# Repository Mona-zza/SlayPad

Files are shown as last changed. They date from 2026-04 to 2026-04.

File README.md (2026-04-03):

# SlayPad

This is a 12key hackpad with 1 rotay Encoder, and 3 RGB LEDs. I've used "XIAO RP2040" microcontroller in it. For the CAD I made it in two parts "Top" and "Bottom". The over all Hackpad looks came up really awsome🎀. I'm so exicted to build this!!!

Currently JLPCB has a sale discount going in it so the PCB in screenshot is $2 cheapper, but I don't know wether that dicount will be there when I'll get the grant so I added $2 extra on PCB to cover it up if I don't get dicount that that moment.

# Images












# BOM

| Name | Purpose | Qty | Total (USD) | Distributor |
|---|---|-----|---|---|
| PCB | PCB | 1 | $15.00 | JLCPCB |
| Keycaps | Keycaps | 12  | $6.56 | Amazon |
| MX-Style switches | Keys | 20  | $6.47 | Amazon |
| 1N4148 Diodes | Diodes | 1 | $1.07 | Amazon |
| MINI-E RGB LEDs | RGB Leds | 1 | $1.24 | Amazon |
| EC11 Rotary Encoders| Volume switch | 1 | $1.86 | Amazon |
| XIAO RP2040 | Microcontroller | 1 | $19.97 | Amazon |
| **TOTAL** | | | **$52.17**  | |

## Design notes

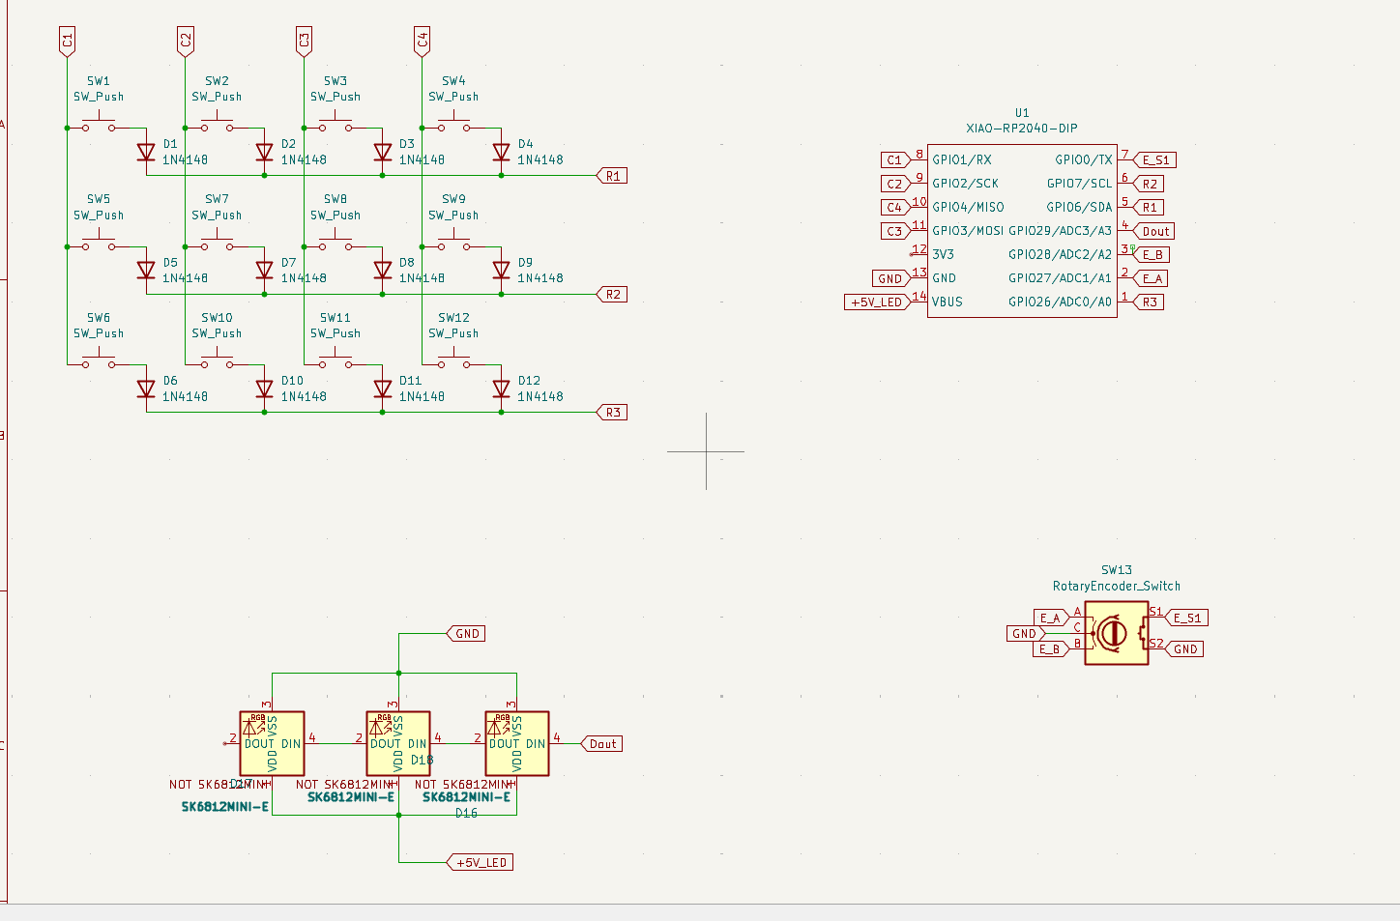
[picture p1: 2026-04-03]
Images/image.png

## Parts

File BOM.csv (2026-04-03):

Name | Purpose | Qty | Total (USD) | Link | Distributor
PCB | PCB | 1 | 15 |  | JLCPCB
Keycaps | Keycaps | 12 | 6.56 | https://www.amazon.in/gp/product/B0FY62LBWH | Amazon
MX-Style switches | Keys | 20 | 6.47 | https://www.amazon.in/gp/product/B0FQBYCGRR | Amazon
1N4148 Diodes | Diodes | 1 | 1.07 | https://www.amazon.in/gp/product/B0G8K9GW3F | Amazon
MINI-E RGB LEDs | RGB Leds | 1 | 1.24 | https://www.amazon.in/gp/product/B07L13JTF4 | Amazon
EC11 Rotary Encoders | Volume switch | 1 | 1.86 | https://www.amazon.in/gp/product/B0888RWNM1 | Amazon
XIAO RP2040 | Microcontroller | 1 | 19.97 | https://www.amazon.in/gp/product/B09NNVNW7M | Amazon
Total |  |  |  | 52.17

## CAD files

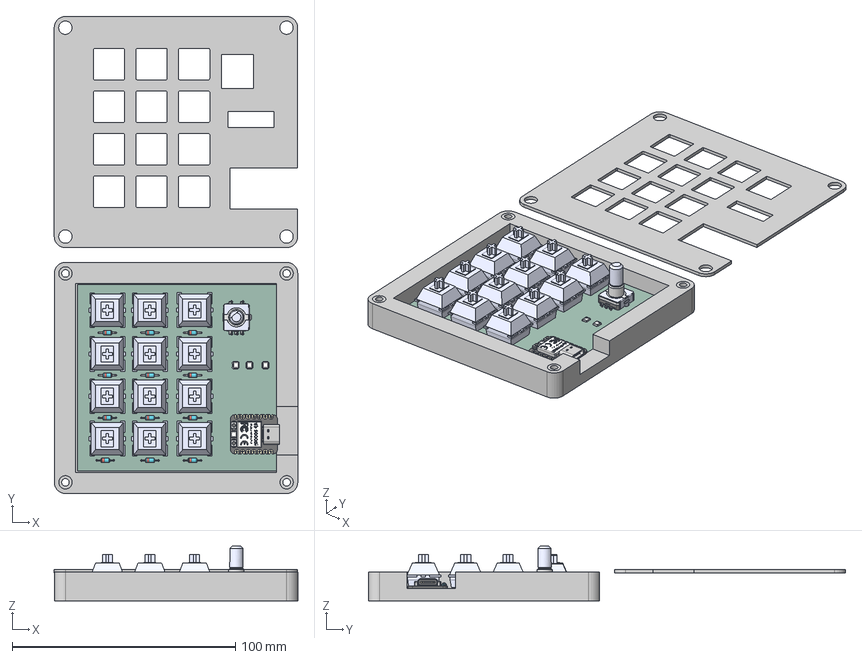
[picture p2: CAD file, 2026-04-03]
CAD/Macropad Assembly - 1.step
109.0 x 213.5 x 24.5 mm
EC11-Shaft-F
EC11-Housing-THT
EC11-Housing-THT_1
EC11-Housing-THT_2
EC11-Housing-THT_3
EC11-Housing-THT_4
EC11-Housing-THT_5
EC11-Housing-THT_6
EC11-Base
Seeed Studio XIAO RP2040 v26_1
Seeed Studio XIAO RP2040 v26_2
Seeed Studio XIAO RP2040 v26_3
Seeed Studio XIAO RP2040 v26_4
Seeed Studio XIAO RP2040 v26_5
Seeed Studio XIAO RP2040 v26_6
Seeed Studio XIAO RP2040 v26_7
Seeed Studio XIAO RP2040 v26_8
Seeed Studio XIAO RP2040 v26_9
Seeed Studio XIAO RP2040 v26_10
Seeed Studio XIAO RP2040 v26_11
Seeed Studio XIAO RP2040 v26_12
Seeed Studio XIAO RP2040 v26_13
Seeed Studio XIAO RP2040 v26_14
Seeed Studio XIAO RP2040 v26_15
Seeed Studio XIAO RP2040 v26_16
Seeed Studio XIAO RP2040 v26_17
Seeed Studio XIAO RP2040 v26_18
Seeed Studio XIAO RP2040 v26_19
Seeed Studio XIAO RP2040 v26_20
Seeed Studio XIAO RP2040 v26_21
Seeed Studio XIAO RP2040 v26_22
Seeed Studio XIAO RP2040 v26_23
Seeed Studio XIAO RP2040 v26_24
Seeed Studio XIAO RP2040 v26_25
Seeed Studio XIAO RP2040 v26_26
Seeed Studio XIAO RP2040 v26_27
Seeed Studio XIAO RP2040 v26_28
Seeed Studio XIAO RP2040 v26_29
Seeed Studio XIAO RP2040 v26_30
Seeed Studio XIAO RP2040 v26_31
Seeed Studio XIAO RP2040 v26_32
Seeed Studio XIAO RP2040 v26_33
Seeed Studio XIAO RP2040 v26_34
Seeed Studio XIAO RP2040 v26_35
Seeed Studio XIAO RP2040 v26_36
type-c v2
smd_button v3(Mirror)
main
main_1
main_2
main_3
type-c v2_1
type-c v2_2
type-c v2_3
type-c v2_4
main_4
main_5
main_6
type-c v2_5
type-c v2_6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

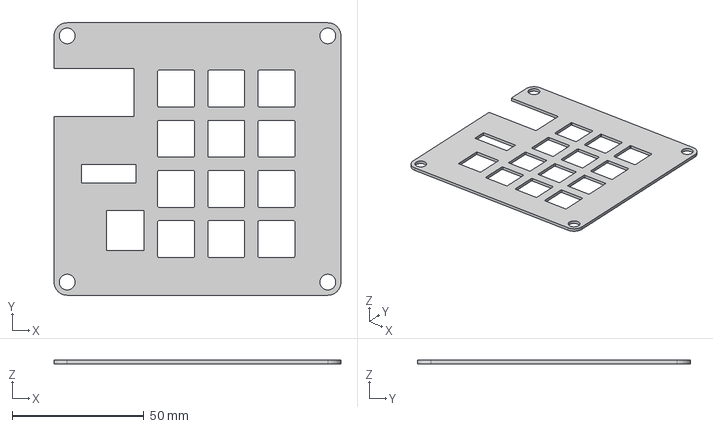
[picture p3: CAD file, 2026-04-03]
CAD/Top #Case.step
109.0 x 103.5 x 1.50 mm

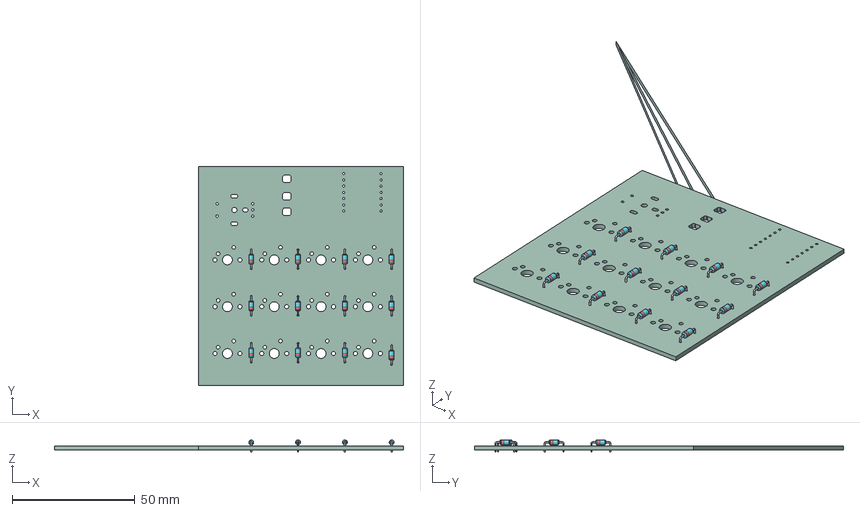
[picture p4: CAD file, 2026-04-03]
CAD/PCB CAD.step
142.0 x 150.2 x 5.01 mm
D_DO-35_SOD27_P7.62mm_Horizontal x 12
PCB_PCB

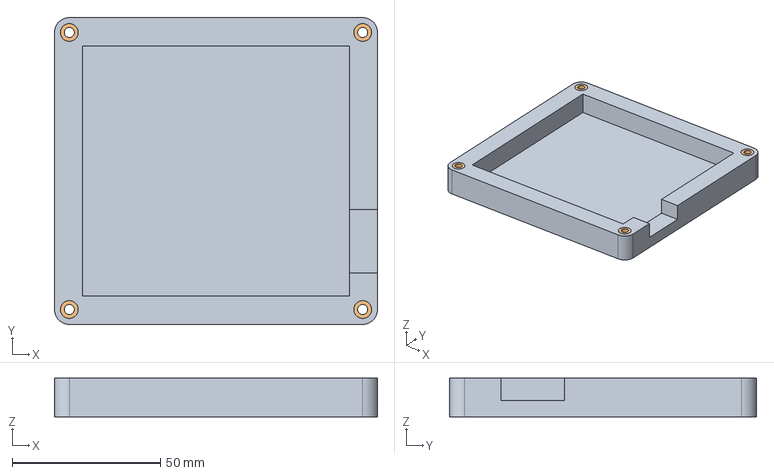
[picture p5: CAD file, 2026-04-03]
CAD/Bottom Base.step
109.0 x 103.5 x 13.0 mm

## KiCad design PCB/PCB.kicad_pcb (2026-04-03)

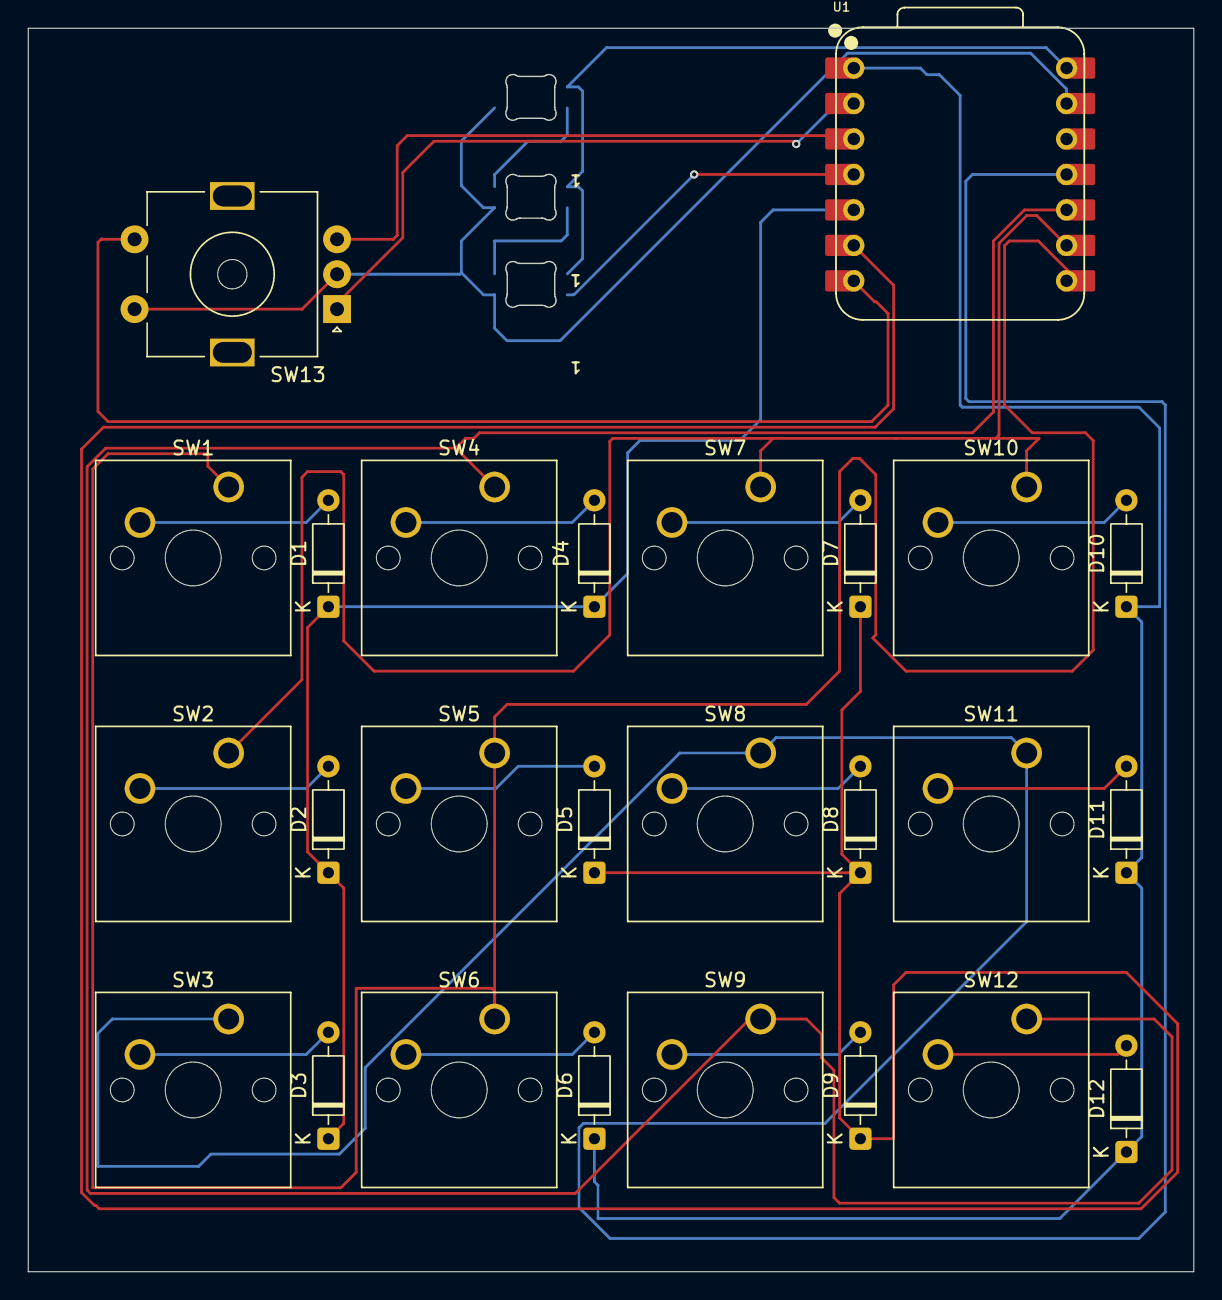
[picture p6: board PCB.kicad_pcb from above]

Board: 2 copper layers, 83.5 x 89.0 mm, 29 parts (0 on the bottom side), 27 nets.

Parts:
D1, D2, D3, D4, D5, D6, D7, D8, D9, D10, D11, D12: 1N4148; D_DO-35_SOD27_P7.62mm_Horizontal
D13, D14, D15: SK6812MINI; MX_SK6812MINI-E_REV
SW1, SW2, SW3, SW4, SW5, SW6, SW7, SW8, SW9, SW10, SW11, SW12: SW_Push; SW_Cherry_MX_1.00u_PCB
SW13: RotaryEncoder_Switch; RotaryEncoder_Alps_EC11E-Switch_Vertical_H20mm_MountingHoles
U1: XIAO-RP2040-DIP

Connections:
+5V_LED: D13.4 (VDD), D14.4 (VDD), D15.4 (VDD), U1.14 (VBUS)
C1: SW1.1, SW5.1, SW6.1, U1.8 (GPIO1/RX)
C2: SW2.1, SW7.1, SW10.1, U1.9 (GPIO2/SCK)
C3: SW3.1, SW8.1, SW11.1, U1.11 (GPIO3/MOSI)
C4: SW4.1, SW9.1, SW12.1, U1.10 (GPIO4/MISO)
Dout: D15.3 (DIN), U1.4 (GPIO29/ADC3/A3)
E_A: SW13.A, U1.2 (GPIO27/ADC1/A1)
E_B: SW13.B, U1.3 (GPIO28/ADC2/A2)
E_S1: SW13.S1, U1.7 (GPIO0/TX)
GND: D13.2 (VSS), D14.2 (VSS), D15.2 (VSS), SW13.C, SW13.S2, U1.13 (GND)
unnamed: D1.2 (A), SW1.2
unnamed: D2.2 (A), SW2.2
unnamed: D3.2 (A), SW3.2
unnamed: D4.2 (A), SW4.2
unnamed: D5.2 (A), SW5.2
unnamed: D6.2 (A), SW6.2
unnamed: D7.2 (A), SW7.2
unnamed: D8.2 (A), SW8.2
unnamed: D9.2 (A), SW9.2
unnamed: D10.2 (A), SW10.2
unnamed: D11.2 (A), SW11.2
unnamed: D12.2 (A), SW12.2
unnamed: D13.3 (DIN), D15.1 (DOUT)
unnamed: D13.1 (DOUT), D14.3 (DIN)
R1: D1.1 (K), D2.1 (K), D3.1 (K), D4.1 (K), U1.5 (GPIO6/SDA)
R2: D5.1 (K), D7.1 (K), D8.1 (K), D9.1 (K), U1.6 (GPIO7/SCL)
R3: D6.1 (K), D10.1 (K), D11.1 (K), D12.1 (K), U1.1 (GPIO26/ADC0/A0)

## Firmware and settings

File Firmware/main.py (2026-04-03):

import board

from kmk.kmk_keyboard import KMKKeyboard
from kmk.scanners.matrix import MatrixScanner
from kmk.keys import KC
from kmk.modules.layers import Layers
from kmk.modules.encoder import EncoderHandler
from kmk.extensions.rgb import RGB


keyboard = KMKKeyboard()


# KEY MATRIX (3 columns x 4 rows)

keyboard.matrix = MatrixScanner(
    row_pins=(
        board.GPIO2,  # R1
        board.GPIO3,  # R2
        board.GPIO4,  # R3
        board.GPIO5,  # R4
    ),
    col_pins=(
        board.GPIO6,  # C1
        board.GPIO7,  # C2
        board.GPIO8,  # C3
    ),
    columns_to_anodes=False, 
)


# LAYERS (MODES)

layers = Layers()
keyboard.modules.append(layers)


# ROTARY ENCODER

encoder = EncoderHandler()
encoder.pins = (
    (board.GPIO9, board.GPIO10),  
)

encoder.map = [
    (KC.VOLD, KC.VOLU),     # Mode 0
    (KC.LEFT, KC.RIGHT),   # Mode 1
    (KC.PGDN, KC.PGUP),    # Mode 2
]

keyboard.modules.append(encoder)


# SK6812 RGB LEDs (3 LEDs, single data pin)

rgb = RGB(
    pixel_pin=board.GPIO11,  
    num_pixels=3,
    hue_default=0,
    sat_default=255,
    val_default=80,
)

keyboard.extensions.append(rgb)


# MODE → LED COLOR INDICATION

def after_layer_change(layer):
    if layer == 0:
        rgb.set_rgb((255, 0, 0))    # Mode 0 → Red
    elif layer == 1:
        rgb.set_rgb((0, 255, 0))    # Mode 1 → Green
    elif layer == 2:
        rgb.set_rgb((0, 0, 255))    # Mode 2 → Blue

keyboard.after_layer_change = after_layer_change


# KEYMAP (3x4)

keyboard.keymap = [

    #          MODE 0 
    [
        KC.Q, KC.W, KC.E,
        KC.A, KC.S, KC.D,
        KC.Z, KC.X, KC.C,
        KC.TO(1), KC.NO, KC.NO,
    ],

    #          MODE 1 
    [
        KC.ONE, KC.TWO, KC.THREE,
        KC.FOUR, KC.FIVE, KC.SIX,
        KC.SEVEN, KC.EIGHT, KC.NINE,
        KC.TO(2), KC.NO, KC.NO,
    ],

    #        MODE 2 
    [
        KC.F1, KC.F2, KC.F3,
        KC.F4, KC.F5, KC.F6,
        KC.F7, KC.F8, KC.F9,
        KC.TO(0), KC.NO, KC.NO,
    ],
]


if __name__ == "__main__":
    after_layer_change(0)  
    keyboard.go()
